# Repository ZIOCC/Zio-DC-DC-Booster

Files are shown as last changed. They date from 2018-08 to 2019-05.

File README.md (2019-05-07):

# Zio DC-DC Booster

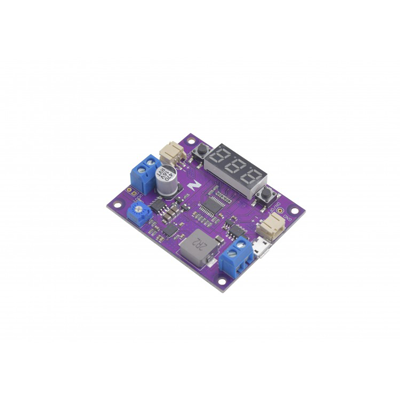
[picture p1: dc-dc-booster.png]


> This product can be available for purchase [here](https://www.smart-prototyping.com/Zio-DC-DC-Booster).

#### Description

The Zio DC-DC is an adjustable voltage booster that can take a 3.7v to 10v input and boost any higher voltage between 5v and 12.5v.

The board features four connectors (one set of screw terminals, two JST PH connectors, and a micro-USB connector) on the input bus, and a set of screw terminals and PTH pads for the output.

Output voltage is adjusted using a potentiometer that can be adjusted with a Phillips or 2mm flathead screwdriver. The 24-segment (3 seven-segment digits and three decimal indicators) display can be toggled using a momentary switch to show the input voltage or output voltage, and a second momentary switch toggles the output on and off.

> Note: This board can only boost, and doesn’t have the ability to regulate the input to lower voltage.

#### Specification

* Booster IC: TPS61088
* Input: 3.7v to 10v
* Output: 5v to 12.5v
* Dimension: 46.8x 56.7mm
* Weight: 20.7g

#### Links

* [Eagle and Schematic file](https://github.com/ZIOCC/Zio-DC-DC-Booster)
* [TPS61088 Datasheet](http://www.ti.com/product/TPS61088/technicaldocuments)
* [Firmware for STM8](https://www.smart-prototyping.com/image/data/NOA-RnD/101917%20DC-DC%20Booster/Zio%20DC-DC%20Booster_firmware.zip)

> ###### About Zio
> Zio is a new line of open sourced, compact, and grid layout boards, fully integrated for Arduino and Qwiic ecosystem. Designed ideally for wearables, robotics, small-space limitations or other on the go projects. Check out other awesome Zio products [here](https://www.smart-prototyping.com/Zio).

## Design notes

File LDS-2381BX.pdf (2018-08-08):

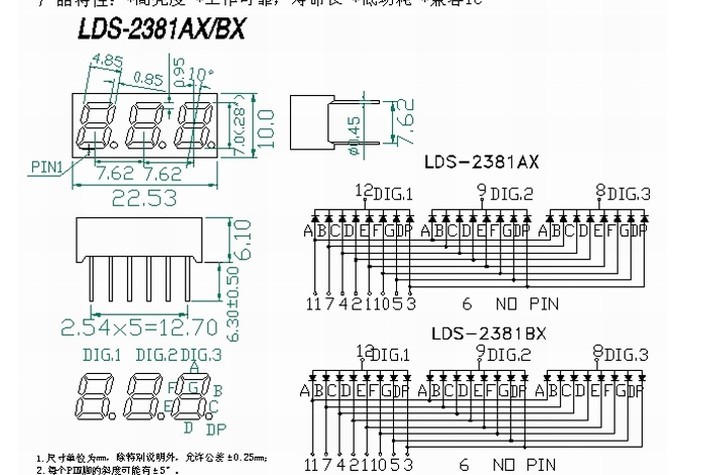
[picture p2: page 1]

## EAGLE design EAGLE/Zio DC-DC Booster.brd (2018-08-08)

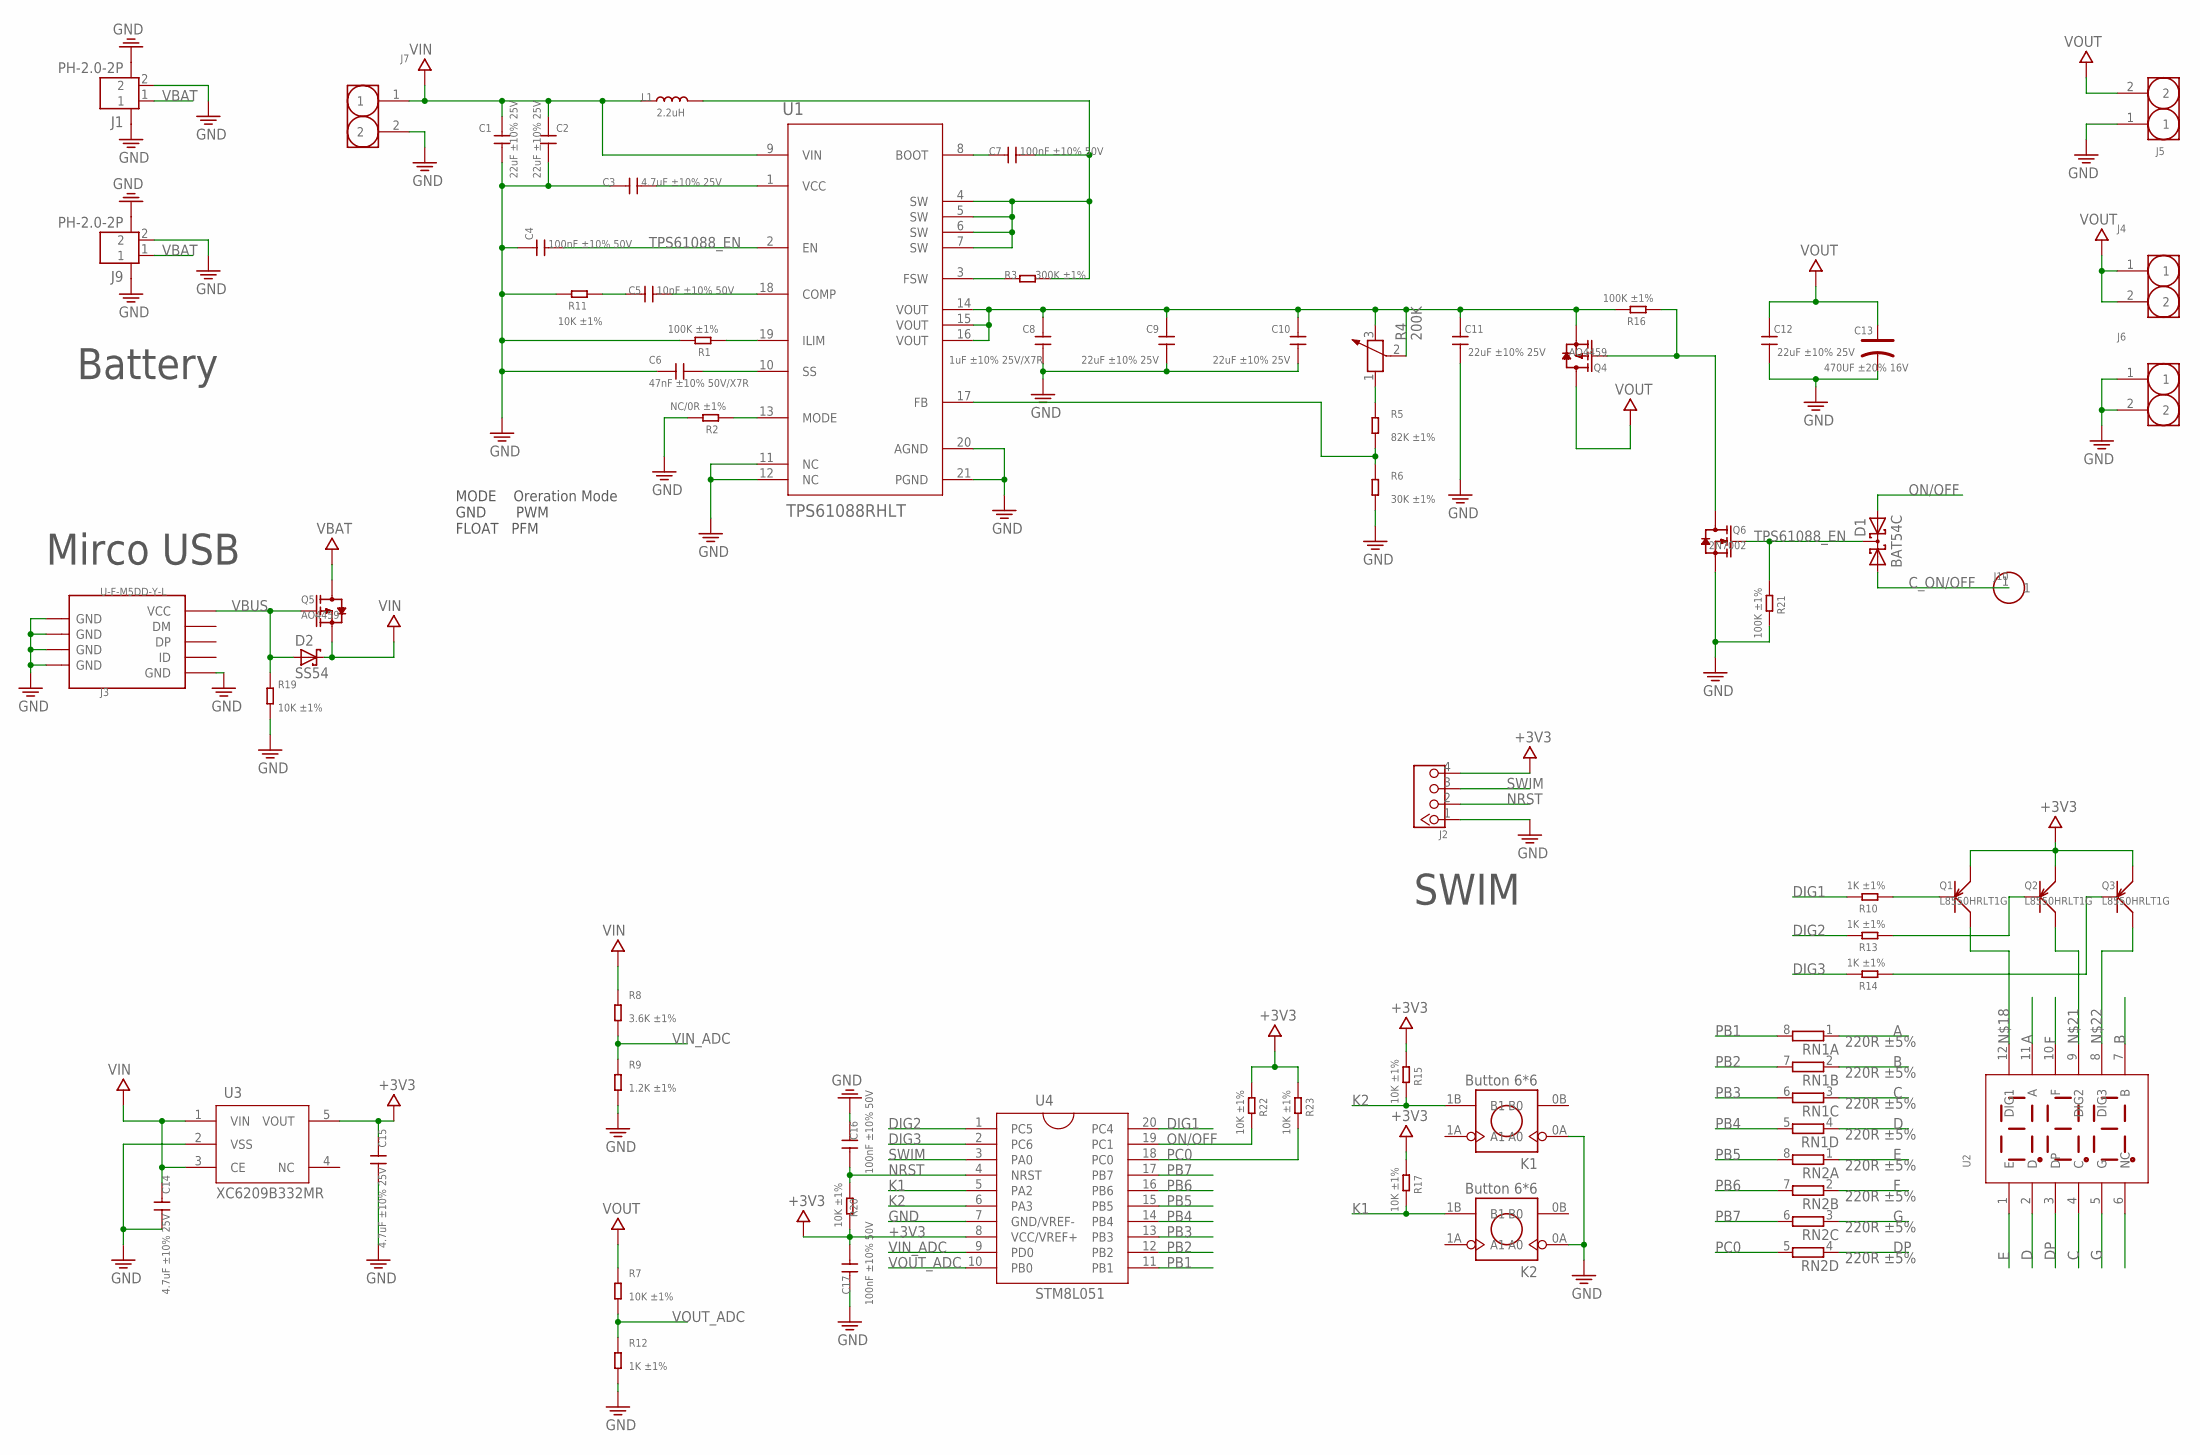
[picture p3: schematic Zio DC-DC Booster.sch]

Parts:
C1, C2, C9, C10, C11, C12: 22uF ±10% 25V; 1206
C3, C14, C15: 4.7uF ±10% 25V; 0603
C4, C7, C16, C17: 100nF ±10% 50V; 0603
C5: 10nF ±10% 50V; 0603
C6: 47nF ±10% 50V/X7R; 0603
C8: 1uF ±10% 25V/X7R; 0603
C13: 470UF ±20% 16V; ELECTRO-SMD-E-7.8MM
D1: BAT54C; SOT23
D2: SS54; SMA
J1, J9: PH-2.0-2P
J2: HEADER-4P-TEST_3.08_4P; TEST_3.08_4P
J3: U-F-M5DD-Y-L; MICRO-SMD
J4, J6: HEADER-2P-65/35MIL; 2P-2.54-65/35MIL
J5, J7: HEADER-2P-SCREW5.0; 2P-SCREW-5.0
J10: HEADER-1P; 1P-40MIL
K1, K2: Button 6*6; 4P-SMD-6X6
L1: 2.2uH; L-10.5*11.5
Q1, Q2, Q3: L8550HRLT1G; SOT23
Q4, Q5: AO4459; SOP08
Q6: 2N7002; SOT23
R1, R16, R21: 100K ±1%; 0603
R2: NC/0R ±1%; 0402
R3: 300K ±1%; 0603
R4: 200K; 3P-SQUA-7X6.8
R5: 82K ±1%; 0603
R6: 30K ±1%; 0603
R7, R11, R15, R17, R19, R20, R22, R23: 10K ±1%; 0603
R8: 3.6K ±1%; 0603
R9: 1.2K ±1%; 0603
R10, R12, R13, R14: 1K ±1%; 0603
RN1, RN2: 220R ±5%; RESISTOR-DIL_0603-ARC
U1: TPS61088RHLT; IC_RHL0020A
U2: SEGMENT_ANODES_3_0.28
U3: XC6209B332MR; SOT23-5
U4: STM8L051; TSSOP20

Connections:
+3V3: C15.1, C17.1, J2.4, Q1.2 (E), Q2.2 (E), Q3.2 (E), R15.2, R17.2, R20.2, R22.2, R23.2, U3.5 (VOUT), U4.8 (VCC/VREF+)
A: RN1.1, U2.11 (A)
B: RN1.2 (1), U2.7 (B)
C: RN1.3 (1), U2.4 (C)
C_ON/OFF: D1.1 (A1), J10.1
D: RN1.4 (1), U2.2 (D)
DIG1: R10.1, U4.20 (PC4)
DIG2: R13.1, U4.1 (PC5)
DIG3: R14.1, U4.2 (PC6)
DP: RN2.4 (1), U2.3 (DP)
E: RN2.1, U2.1 (E)
F: RN2.2 (1), U2.10 (F)
G: RN2.3 (1), U2.5 (G)
GND: C1.2, C2.2, C3.1, C4.1, C6.1, C8.2, C9.2, C10.2, C11.2, C12.2, C13.-, C14.2, C15.2, C16.1, C17.2, J1.2, J1.7 (3), J1.8 (4), J2.1, J3.GND, J3.S1 (GND), J3.S1@1 (GND), J3.S1@2 (GND), J3.S2 (GND), J3.S2@1 (GND), J3.S2@2 (GND), J3.S3 (GND), J3.S3@1 (GND), J3.S3@2 (GND), J3.S4 (GND), J3.S4@1 (GND), J3.S4@2 (GND), J5.1, J6.1, J6.2, J7.2, J9.2, J9.7 (3), J9.8 (4), K1.0A (A0), K2.0A (A0), Q6.2 (S), R1.1, R2.1, R6.2, R9.1, R11.1, R12.1, R19.2, R21.1, U1.11 (NC), U1.12 (NC), U1.20 (AGND), U1.21 (PGND), U3.2 (VSS), U4.7 (GND/VREF-)
K1: K2.1B (B1), R17.1, U4.5 (PA2)
K2: K1.1B (B1), R15.1, U4.6 (PA3)
unnamed: R4.1, R5.1
unnamed: Q1.1 (B), R10.2
unnamed: Q2.1 (B), R13.2
unnamed: Q3.1 (B), R14.2
unnamed: Q4.4 (G), Q6.3 (D), R16.2
unnamed: C5.1, R11.2
unnamed: C5.2, U1.18 (COMP)
unnamed: Q1.3 (C), U2.12 (DIG1)
unnamed: Q2.3 (C), U2.9 (DIG2)
unnamed: Q3.3 (C), U2.8 (DIG3)
unnamed: C3.2, U1.1 (VCC)
unnamed: C7.1, U1.8 (BOOT)
unnamed: R3.1, U1.3 (FSW)
unnamed: R5.2, R6.1, U1.17 (FB)
unnamed: R2.2, U1.13 (MODE)
unnamed: C6.2, U1.10 (SS)
unnamed: R1.2, U1.19 (ILIM)
NRST: C16.2, J2.2, R20.1, U4.4 (NRST)
ON/OFF: D1.2 (A2), R22.1, U4.19 (PC1)
PB1: RN1.8 (2), U4.11 (PB1)
PB2: RN1.7 (2), U4.12 (PB2)
PB3: RN1.6 (2), U4.13 (PB3)
PB4: RN1.5 (2), U4.14 (PB4)
PB5: RN2.8 (2), U4.15 (PB5)
PB6: RN2.7 (2), U4.16 (PB6)
PB7: RN2.6 (2), U4.17 (PB7)
PC0: R23.1, RN2.5 (2), U4.18 (PC0)
SW: C7.2, L1.2, R3.2, U1.4 (SW), U1.5 (SW), U1.6 (SW), U1.7 (SW)
SWIM: J2.3, U4.3 (PA0)
TPS61088_EN: C4.2, D1.3 (CC), Q6.1 (G), R21.2, U1.2 (EN)
VBAT: J1.1, J9.1, Q5.5 (D), Q5.6 (D), Q5.7 (D), Q5.8 (D)
VBUS: D2.P$2 (A), J3.VBUS (VCC), Q5.4 (G), R19.1
VIN: C1.1, C2.1, C14.1, D2.P$1 (C), J7.1, L1.1, Q5.1 (S), Q5.2 (S), Q5.3 (S), R8.2, U1.9 (VIN), U3.1 (VIN), U3.3 (CE)
VIN_ADC: R8.1, R9.2, U4.9 (PD0)
VOUT: C12.1, C13.+, J4.1, J4.2, J5.2, Q4.5 (D), Q4.6 (D), Q4.7 (D), Q4.8 (D), R7.2
VOUT_ADC: R7.1, R12.2, U4.10 (PB0)
V_OUT: C8.1, C9.1, C10.1, C11.1, Q4.1 (S), Q4.2 (S), Q4.3 (S), R4.2, R4.3, R16.1, U1.14 (VOUT), U1.15 (VOUT), U1.16 (VOUT)

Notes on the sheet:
Battery
SWIM
Mirco USB
MODE Oreration Mode GND PWM FLOAT PFM

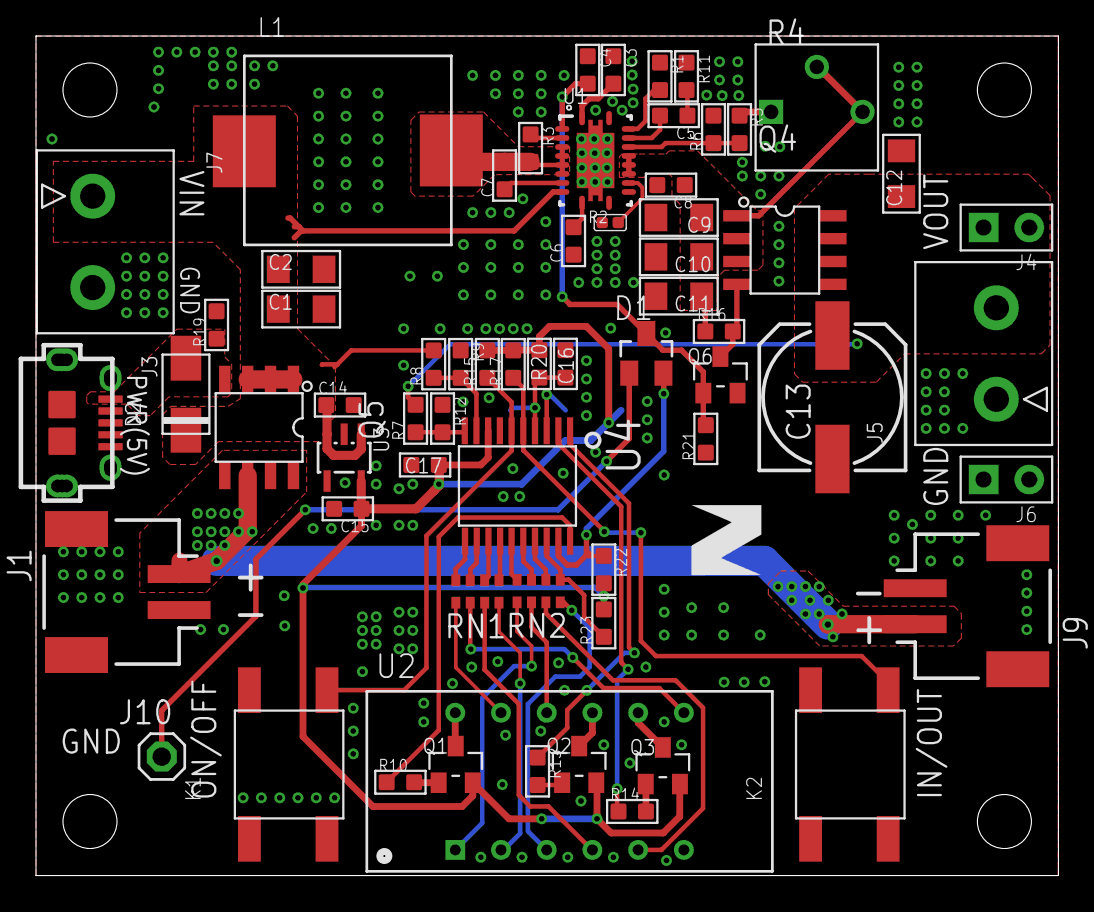
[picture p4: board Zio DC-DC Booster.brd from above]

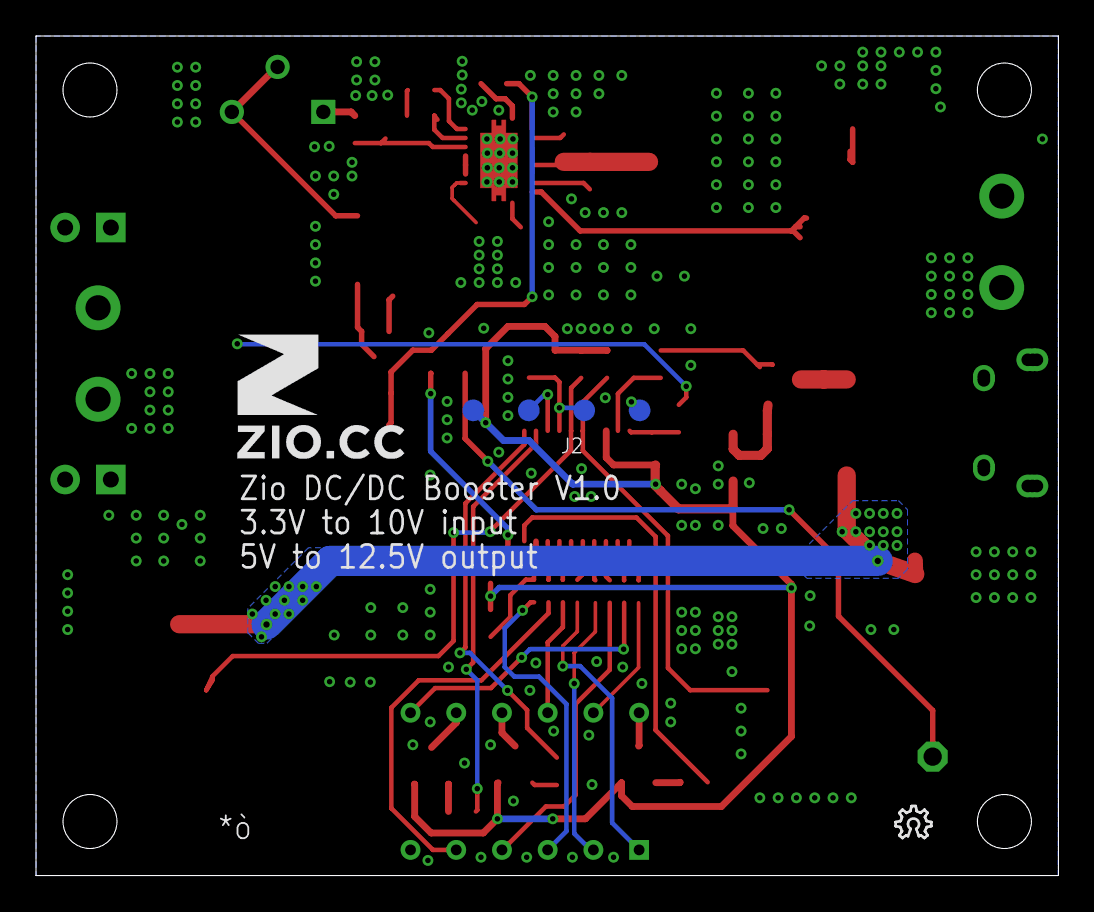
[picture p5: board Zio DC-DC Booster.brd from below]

Board: 2 copper layers, 56.8 x 46.6 mm, 68 parts (3 on the bottom side), 53 nets.

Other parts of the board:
LOGO1: LOGO-OSHW-6MILX0070-NT; OSHW_6X70_NOTEXT
U$2: 6MM
U$3: 7MM
